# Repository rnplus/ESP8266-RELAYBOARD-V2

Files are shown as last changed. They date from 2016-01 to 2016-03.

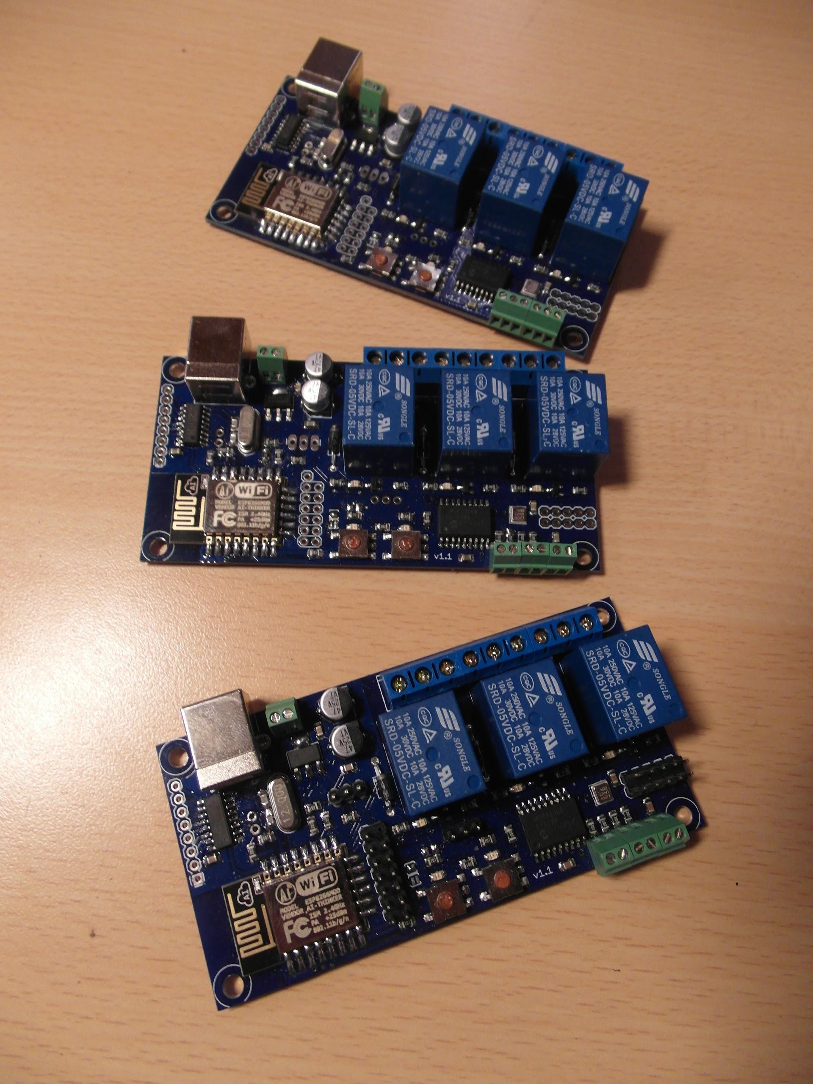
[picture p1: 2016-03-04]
photo.jpg

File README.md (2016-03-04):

# esp8266-relayboard-pka
New ESP8266 based wifi relay board. Has 3 relay switches and a BMP180 air pressure sensor

# Versions
Revision 1 is the version that I built. There is a small mistake in the schematic: the pull-up resistor of the reset pin is on the wrong side of the jumper that selects which function the reset/gpio2 button has.
I fixed this mistake in revision 2 but I did not test that new version of the design, so use at your own risk.

License: CC BY-SA 3.0

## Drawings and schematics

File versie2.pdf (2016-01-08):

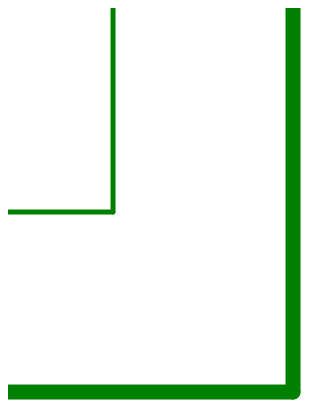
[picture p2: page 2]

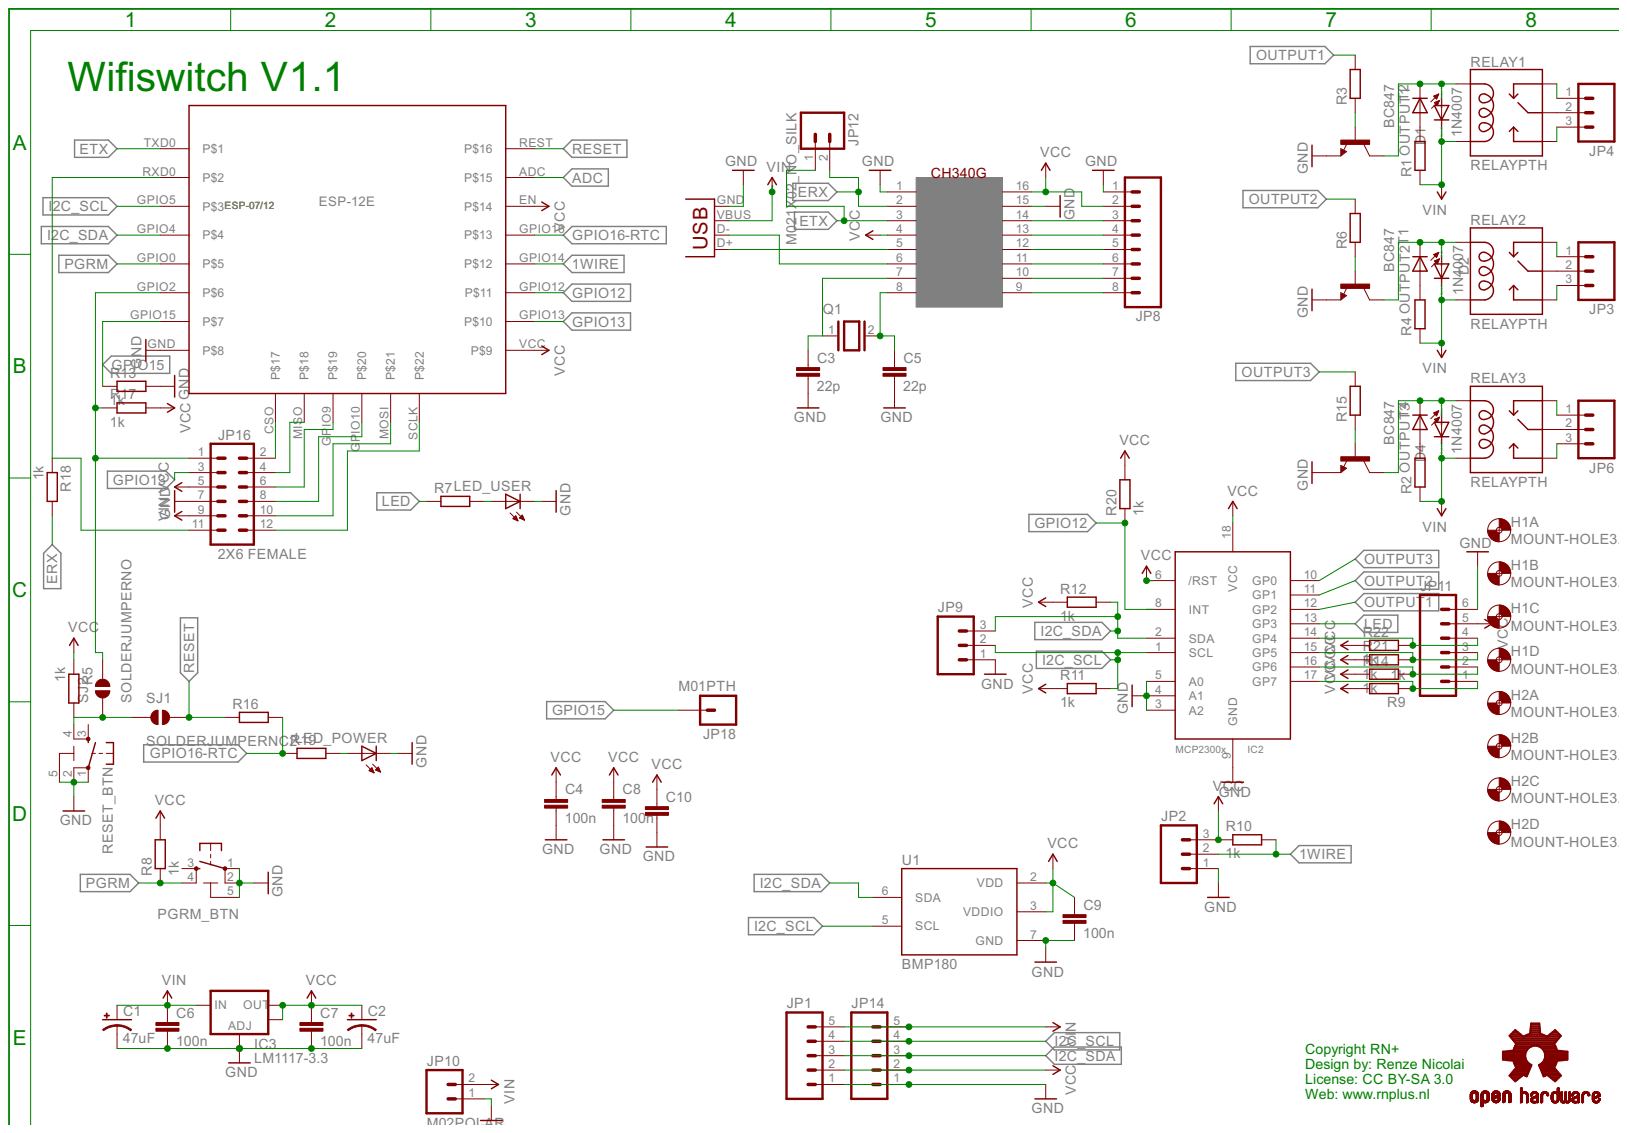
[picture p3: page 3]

SpiceOrder 1 SpiceOrder 2 SpiceOrder 1 SpiceOrder 2 SpiceOrder 1 SpiceOrder 2

Copyright RN+ Design by: Renze Nicolai

License: CC BY-SA 3.0
Web: www.rnplus.nl

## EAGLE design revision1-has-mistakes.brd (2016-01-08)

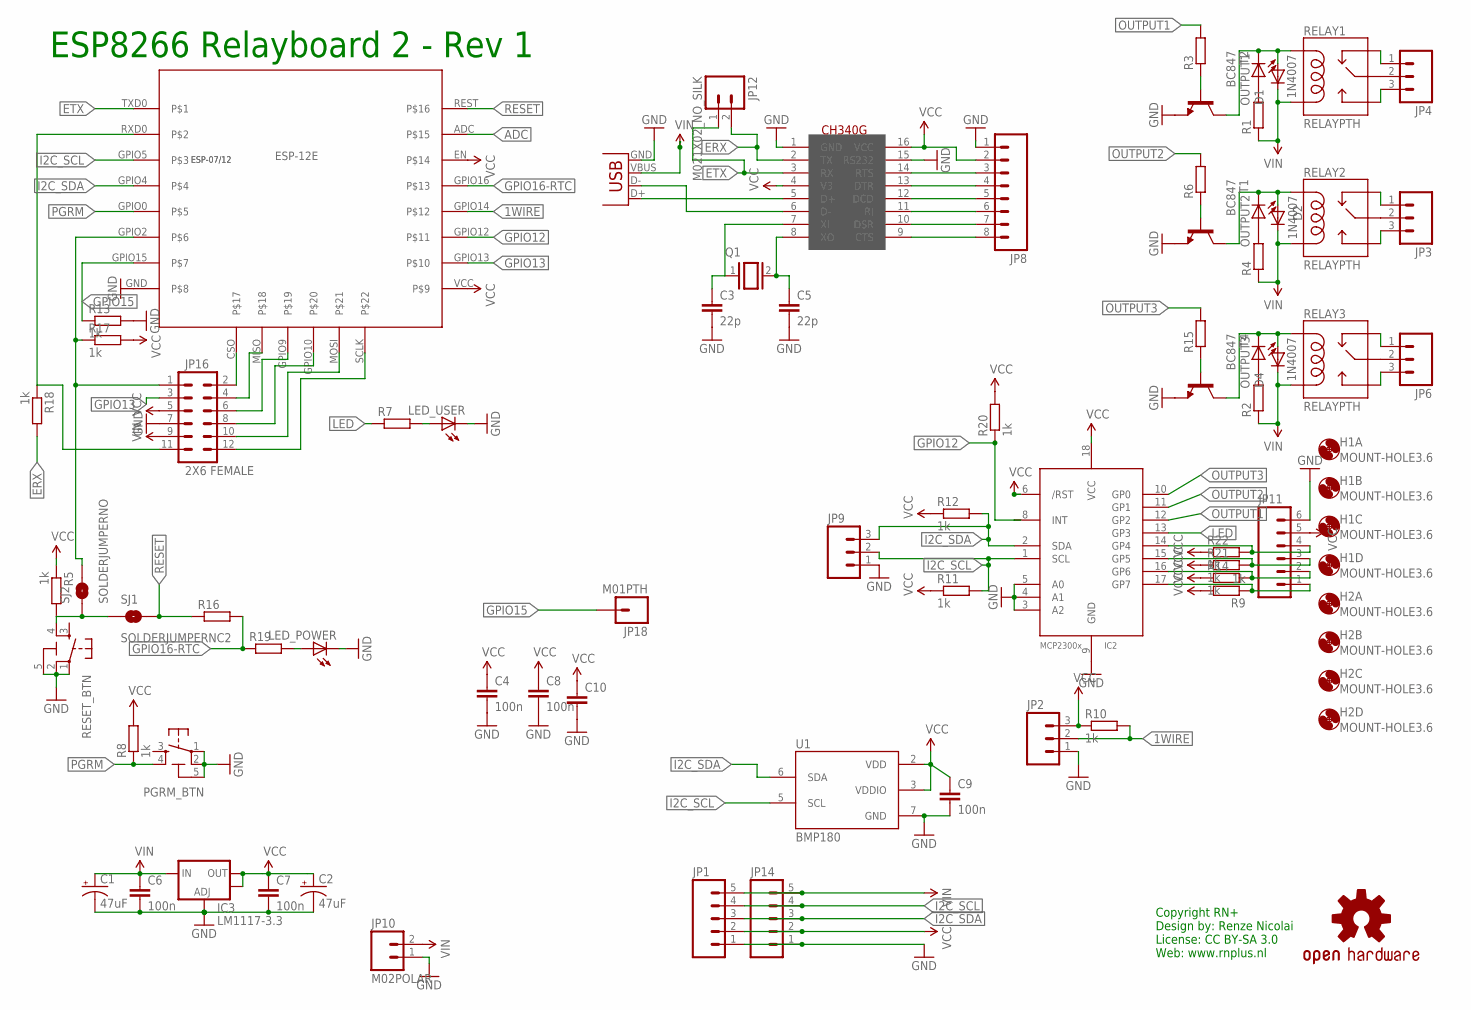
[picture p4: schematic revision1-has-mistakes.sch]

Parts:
C1, C2: 47uF; PANASONIC_D
C3, C5: 22p; C0805K
C4, C6, C7, C8, C9: 100n; C0805K
C10: C-EUC0805K; C0805K
D1, D2, D4: 1N4942; DO41-10
H1A, H1B, H1C, H1D, H2A, H2B, H2C, H2D: MOUNT-HOLE3.6; 3,6
IC2: MCP23008/SO; SO18W
IC3: LM1117-3.3; SOT223
JP1, JP14: M05PTH; 1X05
JP2: M03LONGPADS; 1X03_LONGPADS
JP3, JP4, JP6: M03-SCREW-5MM; SCREWTERMINAL-5MM-3
JP5: USB-B; USB-B-PTH
JP8: M08SILK_FEMALE_PTH; 1X08
JP9: M031X03_NO_SILK; 1X03_NO_SILK
JP10: M02POLAR; MOLEX-1X2
JP11: M06LONGPADS; 1X06_LONGPADS
JP12: M021X02_NO_SILK; 1X02_NO_SILK
JP16: 2X6 FEMALE; 2X6
JP18: M01PTH; 1X01
LED_POWER: LEDCHIP-LED0805; CHIP-LED0805
LED_USER: LEDCHIP-LED0805; CHIP-LED0805
LOGO1: OSHW-LOGOL; OSHW-LOGO-L
OUTPUT1, OUTPUT2, OUTPUT3: LEDCHIP-LED0805; CHIP-LED0805
PGRM_BTN: SMARTPRJ_TS42
Q1: XTAL/S; QS
R1, R2, R3, R4, R6, R7, R15, R16, R19: SMARTPRJ_R-EU_M0805; SMARTPRJ_M0805
R5, R8, R9, R10, R11, R12, R13, R14, R17, R18, R20, R21, R22: 1k; SMARTPRJ_M0805
RELAY1, RELAY2, RELAY3: RELAYPTH; SRD-05VDC-SL-C
RESET_BTN: SMARTPRJ_TS42
SJ1: SOLDERJUMPERNC2; SJ_2S-NOTRACE
SJ2: SOLDERJUMPERNO; SJ_2S-NO
T1, T2, T4: BC847; SOT23
U1: BMP180
U$1: CH340G; SOIC16
U$2: ESP-07/12_ESP-12E; ESP-07/12

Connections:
1WIRE: JP2.2, R10.2, U$2.GPIO14
ADC: U$2.ADC
ERX: JP12.2, R18.2, U$1.2 (TX)
ERXR: JP16.11, R18.1, U$2.RXD0
ETX: JP12.1, U$1.3 (RX), U$2.TXD0
GND: C1.-, C2.-, C3.2, C4.2, C5.2, C6.2, C7.2, C8.2, C9.2, C10.2, IC2.3 (A2), IC2.4 (A1), IC2.5 (A0), IC2.9 (GND), IC3.1 (ADJ), JP1.1, JP2.1, JP5.GND, JP8.1, JP9.1, JP10.1, JP11.6, JP14.1, JP16.7, LED_POWER.C, LED_USER.C, PGRM_BTN.1, PGRM_BTN.2, PGRM_BTN.5 (5-GND), R13.2, RESET_BTN.1, RESET_BTN.2, RESET_BTN.5 (5-GND), T1.2 (E), T2.2 (E), T4.2 (E), U1.7 (GND), U$1.1 (GND), U$1.15 (RS232), U$2.GND
GPIO12: IC2.8 (INT), R20.1, U$2.GPIO12
GPIO13: JP16.3, U$2.GPIO13
GPIO15: JP18.1, R13.1, U$2.GPIO15
GPIO16-RTC: R16.2, R19.1, U$2.GPIO16
I2C_SCL: IC2.1 (SCL), JP1.4, JP9.2, JP14.4, R11.2, U1.5 (SCL), U$2.GPIO5
I2C_SDA: IC2.2 (SDA), JP1.3, JP9.3, JP14.3, R12.2, U1.6 (SDA), U$2.GPIO4
LED: IC2.13 (GP3), R7.1
unnamed: D2.A, OUTPUT2.C, RELAY2.COIL1, T1.3 (C)
unnamed: D1.A, OUTPUT1.C, RELAY1.COIL1, T2.3 (C)
unnamed: JP3.2, RELAY2.SWCOMMON
unnamed: JP4.2, RELAY1.SWCOMMON
unnamed: JP4.1, RELAY1.SWCLOSED (SWCLOSE)
unnamed: JP4.3, RELAY1.SWOPEN
unnamed: JP3.3, RELAY2.SWOPEN
unnamed: JP3.1, RELAY2.SWCLOSED (SWCLOSE)
unnamed: R3.1, T2.1 (B)
unnamed: R6.1, T1.1 (B)
unnamed: R5.2, RESET_BTN.4, SJ1.1, SJ2.1
unnamed: OUTPUT2.A, R4.2
unnamed: IC2.14 (GP4), JP11.4, R22.2
unnamed: LED_USER.A, R7.2
unnamed: OUTPUT1.A, R1.2
unnamed: D4.A, OUTPUT3.C, RELAY3.COIL1, T4.3 (C)
unnamed: R15.1, T4.1 (B)
unnamed: IC2.15 (GP5), JP11.3, R21.2
unnamed: C3.1, Q1.1, U$1.7 (XI)
unnamed: OUTPUT3.A, R2.2
unnamed: C5.1, Q1.2, U$1.8 (XO)
unnamed: JP6.2, RELAY3.SWCOMMON
unnamed: JP6.1, RELAY3.SWCLOSED (SWCLOSE)
unnamed: JP6.3, RELAY3.SWOPEN
unnamed: JP8.5, U$1.12 (DCD)
unnamed: JP8.4, U$1.13 (DTR)
unnamed: JP8.3, U$1.14 (RTS)
unnamed: JP8.8, U$1.9 (CTS)
unnamed: JP8.7, U$1.10 (DSR)
unnamed: JP8.6, U$1.11 (RI)
unnamed: LED_POWER.A, R19.2
unnamed: JP16.2, U$2.CSO
unnamed: JP16.4, U$2.MISO
unnamed: JP16.6, U$2.GPIO9
unnamed: JP16.8, U$2.GPIO10
unnamed: JP16.10, U$2.MOSI
unnamed: JP16.12, U$2.SCLK
unnamed: JP16.1, R17.1, SJ2.2, U$2.GPIO2
OUTPUT1: IC2.12 (GP2), R3.2
OUTPUT2: IC2.11 (GP1), R6.2
OUTPUT3: IC2.10 (GP0), R15.2
PGRM: PGRM_BTN.4, R8.1, U$2.GPIO0
RESET: R16.1, SJ1.2, U$2.REST
SENSOR1: IC2.16 (GP6), JP11.2, R14.2
SENSOR2: IC2.17 (GP7), JP11.1, R9.1
USB_N: JP5.D-, U$1.6 (D-)
USB_P: JP5.D+, U$1.5 (D+)
VCC: C2.+, C4.1, C7.1, C8.1, C9.1, C10.1, IC2.6 (/RST), IC2.18 (VCC), IC3.2 (OUT), IC3.4 (OUT), JP1.2, JP2.3, JP8.2, JP11.5, JP14.2, JP16.5, R5.1, R8.2, R9.2, R10.1, R11.1, R12.1, R14.1, R17.2, R20.2, R21.1, R22.1, U1.2 (VDD), U1.3 (VDDIO), U$1.4 (V3), U$1.16 (VCC), U$2.EN, U$2.VCC
VIN: C1.+, C6.1, D1.C, D2.C, D4.C, IC3.3 (IN), JP1.5, JP5.VBUS, JP10.2, JP14.5, JP16.9, R1.1, R2.1, R4.1, RELAY1.COIL0, RELAY2.COIL0, RELAY3.COIL0

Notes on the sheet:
Copyright RN+ Design by: Renze Nicolai License: CC BY-SA 3.0 Web: www.rnplus.nl
ESP8266 Relayboard 2 - Rev 1
1N4007

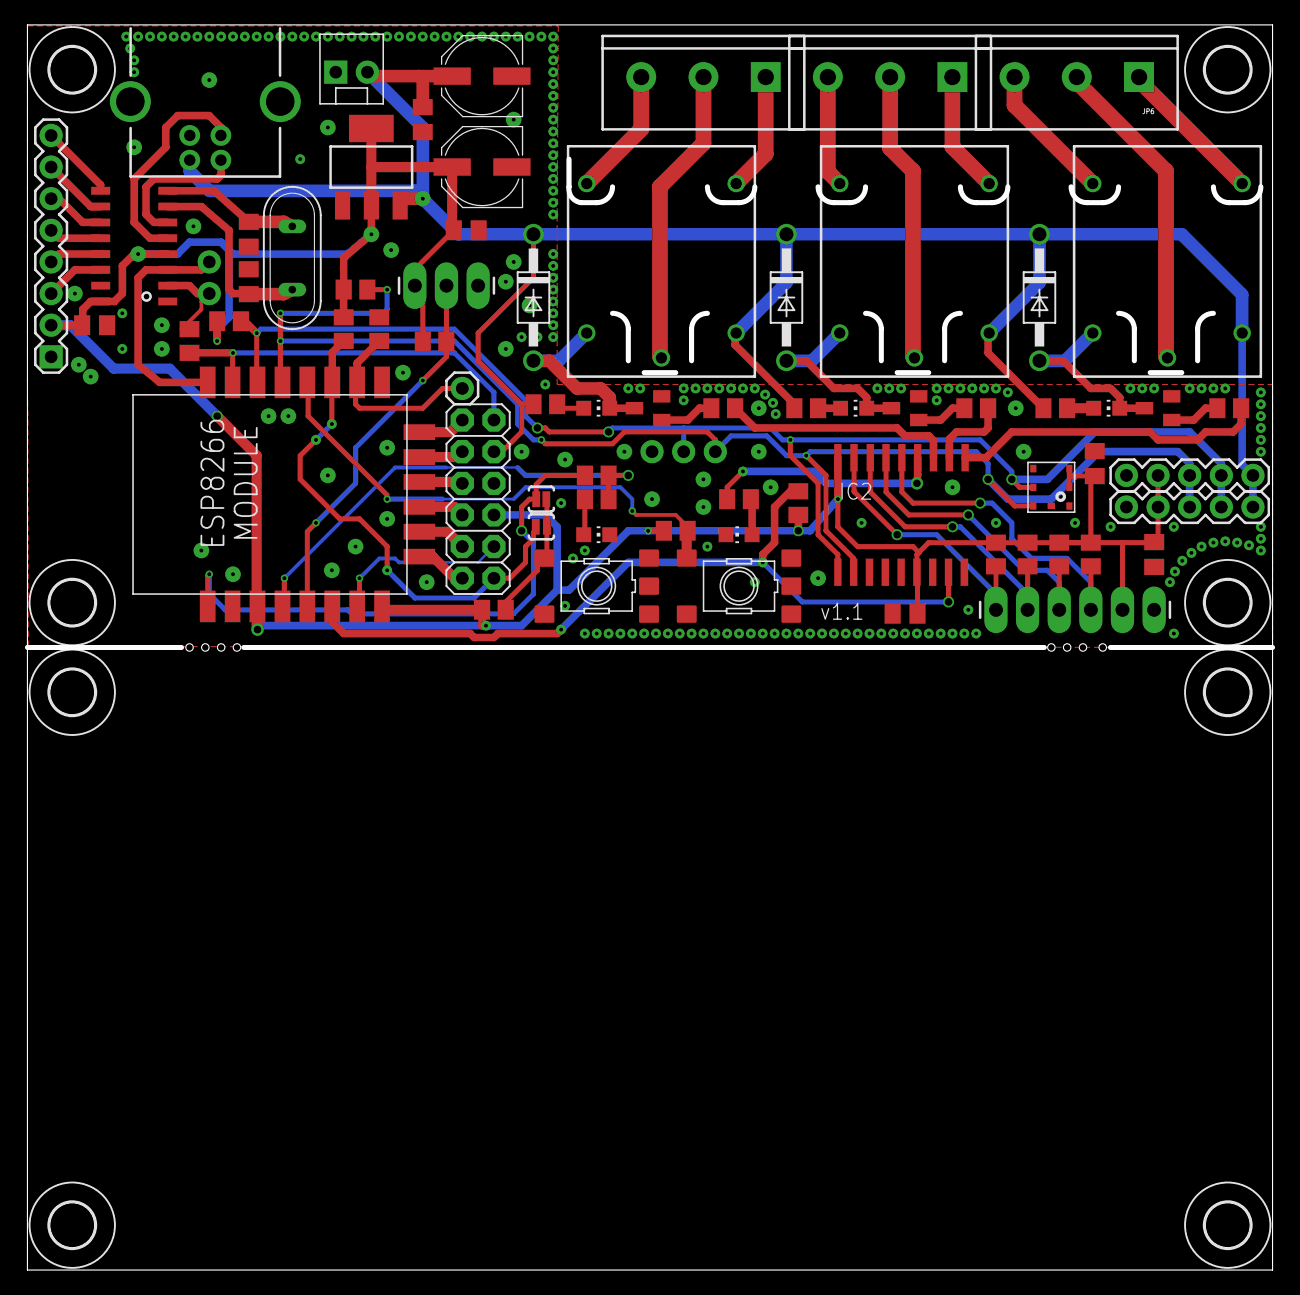
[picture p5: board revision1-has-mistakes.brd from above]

Board: 2 copper layers, 100.0 x 100.0 mm, 79 parts (1 on the bottom side), 61 nets.

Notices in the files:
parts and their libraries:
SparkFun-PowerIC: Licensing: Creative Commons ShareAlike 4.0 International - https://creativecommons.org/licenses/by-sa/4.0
